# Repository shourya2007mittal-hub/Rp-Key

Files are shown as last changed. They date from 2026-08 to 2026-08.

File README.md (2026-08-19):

# Rp-Key



SO I wanted to make something like YubiKey but to Enter passwords onto your online accounts or offline password ( like laptop passwords / security passwords) and the most important thing that I focused was that you could enter a password in public without anyone watching it . This add extra privacy to your workflow . So the main focus of my design was to make it small . SO I used RP2350A as micro-controller because it doesn't need an external oscillator hence it saves space on the board . Also there are 4 switches . So you could enter upto 4 different passwords as per your need . There is a boot pin also so that you could update the board as per your need .  The Design is compatible with USB-A and it plugs in perfectly onto it with all the connectors pins aligned . other then that the board has a 3.3V voltage regulator for the MCU and a LED. 

## Why This

It is a simple and is compile too that can be directly plugged on Laptop to enter a password also no one would see you entering the password so it's even better. 

## Features

- Based on RP-2035A Chip
- Has MCP1700x-330xxTT as Voltage Regulator
- has 4 button to enter 4 different password
- had a boot pin as well to update password
- Plugs directly onto type A female

# Project Bill of Materials (BOM) & Cost Summary

## 📦 Components List

| Comment / Part | Quantity | Total Price ($) | Part Link |
| :--- | :---: | :---: | :--- |
| **4.7u** | 6 | $0.1368 | [JLCPCB Link](https://jlcpcb.com/partdetail/24469-CL05A475MP5NRNC/C23733) |
| **100n** | 4 | $0.0216 | [JLCPCB Link](https://jlcpcb.com/partdetail/1877-CL05B104KO5NNNC/C1525) |
| **10uF** | 4 | $0.1548 | [JLCPCB Link](https://jlcpcb.com/partdetail/20411-CL10A106KP8NNNC/C19702) |
| **15p** | 4 | $0.0188 | [JLCPCB Link](https://jlcpcb.com/partdetail/1900-0402CG150J500NT/C1548) |
| **3.3u** | 2 | $1.6456 | [JLCPCB Link](https://jlcpcb.com/partdetail/KOHERelec-MDA40203R3M/C2847470) |
| **1k** | 4 | $0.0320 | [JLCPCB Link](https://jlcpcb.com/partdetail/12256-0402WGF1001TCE/C11702) |
| **10k** | 2 | $0.0132 | [JLCPCB Link](https://jlcpcb.com/partdetail/26274-0402WGJ0103TCE/C25531) |
| **27 ohm** | 4 | $0.0362 | [JLCPCB Link](https://jlcpcb.com/partdetail/25843-0402WGF270JTCE/C25100) |
| **33** | 2 | $0.0068 | [JLCPCB Link](https://jlcpcb.com/partdetail/25848-0402WGF330JTCE/C25105) |
| **1K** | 2 | $0.0120 | [JLCPCB Link](https://jlcpcb.com/partdetail/21904-0603WAF1001T5E/C21190) |
| **SW_Push** | 10 | $3.7180 | [JLCPCB Link](https://jlcpcb.com/partdetail/Korean_HropartsElec-K5_1672SN01/C502360) |
| **RP2350A** | 2 | $3.3980 | [JLCPCB Link](https://jlcpcb.com/partdetail/RaspberryPi-RP2350A/C42411118) |
| **MCP1700x-330xxTT** | 2 | $1.0314 | [JLCPCB Link](https://jlcpcb.com/partdetail/MicrochipTech-MCP1700_3002ETO/C185558) |
| **ABM8-272-T3** | 5 | $1.4705 | [JLCPCB Link](https://jlcpcb.com/partdetail/AbraconLLC-ABM8_272T3/C20625731) |
| **USB_A_PCB_Edge_receptacle** | - | - | - |

---

## 💰 Charge Details & Manufacturing Breakdown

### 🛠️ PCB Fabrication & Assembly Fees
| Item / Description | Price ($) |
| :--- | :---: |
| **PCB Base Price** | $2.00 |
| **Via Covering** | $0.00 |
| **Special Offer** | $2.00 |
| **Setup Fee** | $8.18 |
| **Stencil** | $1.53 |
| **Panel** | $0.00 |
| **Large Size** | $0.00 |
| **Components (12 items)** | $11.65 |
| **Extended components fee** | $12.28 |
| **SMT Assembly** | $0.38 |
| **Hand-soldering labor fee** | $3.58 |
| **Manual Assembly** | $0.10 |
| **Nitrogen reflow soldering** | $0.85 |

### 💵 Cost Totals Summary
| Category | Total Price ($) |
| :--- | :---: |
| **PCB Price Total** | **$2.00** |
| **PCB Shipping** | **$9.68** |
| **Economic PCBA Price Total** | **$48.23** |
| **Grand Total** | **$50.23** |

### Schematic 
<br>



<br>

### PCB Design



### 3D Design



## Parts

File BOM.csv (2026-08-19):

Comment / Item | Quantity | Total Price ($) | Link
4.7u | 6 | 0.1368 | https://jlcpcb.com/partdetail/24469-CL05A475MP5NRNC/C23733
100n | 4 | 0.0216 | https://jlcpcb.com/partdetail/1877-CL05B104KO5NNNC/C1525
10uF | 4 | 0.1548 | https://jlcpcb.com/partdetail/20411-CL10A106KP8NNNC/C19702
10uF | 6 | 0.1548 | https://jlcpcb.com/partdetail/20411-CL10A106KP8NNNC/C19702
15p | 4 | 0.0188 | https://jlcpcb.com/partdetail/1900-0402CG150J500NT/C1548
3.3u | 2 | 1.6456 | https://jlcpcb.com/partdetail/KOHERelec-MDA40203R3M/C2847470
1k | 4 | 0.0320 | https://jlcpcb.com/partdetail/12256-0402WGF1001TCE/C11702
33 | 2 | 0.0068 | https://jlcpcb.com/partdetail/25848-0402WGF330JTCE/C25105
1K | 2 | 0.0120 | https://jlcpcb.com/partdetail/21904-0603WAF1001T5E/C21190
10k | 2 | 0.0132 | https://jlcpcb.com/partdetail/26274-0402WGJ0103TCE/C25531
27 ohm | 4 | 0.0362 | https://jlcpcb.com/partdetail/25843-0402WGF270JTCE/C25100
SW_Push | 4 | 3.7180 | https://jlcpcb.com/partdetail/Korean_HropartsElec-K5_1672SN01/C502360
RP2350A | 2 | 3.3980 | https://jlcpcb.com/partdetail/RaspberryPi-RP2350A/C42411118
MCP1700x-330xxTT | 2 | 1.0314 | https://jlcpcb.com/partdetail/MicrochipTech-MCP1700_3002ETO/C185558
ABM8-272-T3 | 5 | 1.4705 | https://jlcpcb.com/partdetail/AbraconLLC-ABM8_272T3/C20625731
USB_A_PCB_Edge_receptacle | - | - | -
--- CHARGE DETAILS --- | --- | --- | ---
PCB Base Price | - | 2.00 | -
Via Covering | - | 0.00 | -
Special Offer | - | 2.00 | -
Setup Fee | - | 8.18 | -
Stencil | - | 1.53 | -
Panel | - | 0.00 | -
Large Size | - | 0.00 | -
Components (12 items) | - | 11.65 | -
Extended components fee | - | 12.28 | -
SMT Assembly | - | 0.38 | -
Hand-soldering labor fee | - | 3.58 | -
Manual Assembly | - | 0.10 | -
Nitrogen reflow soldering | - | 0.85 | -
PCB Price Total | - | 2.00 | -
PCB Shipping | - | 9.68 | -
Economic PCBA Price Total | - | 48.23 | -
Grand Total | - | 50.23 | -

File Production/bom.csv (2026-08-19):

Designator | Footprint | Quantity | Value | LCSC Part #
C1, C2, C3 | 0402 | 3 | 4.7u
C6, C7, C8, C9, C10, C11 | 0402 | 6 | 10uf
C13, C14 | 0603 | 2 | 10uF
C29, C30 | 0402 | 2 | 15p
C4, C5 | 0402 | 2 | 100n
D1 | 0201 | 1 | LED
J1 | USB_A_PCB_Edge_receptacle | 1 | USB_A_PCB_Edge_receptacle
L1 | 0402 | 1 | 3.3u
R1, R2 | 0402 | 2 | 1k
R11 | 0603 | 1 | 1K
R3 | 0402 | 1 | 33
R5 ,R6 | 0402 | 2 | 27 ohm
SW13, SW14 | SW_Tactile_SPST_NO_Straight_CK_PTS636Sx25SMTRLFS | 2 | SW_Push
U1 | QFN-60-1EP_7x7mm_P0.4mm_EP3.4x3.4mm | 1 | RP2350A
U3 | SOT-23 | 1 | MCP1700x-330xxTT
Y2 | Crystal_SMD_3225-4Pin_3.2x2.5mm | 1 | ABM8-272-T3

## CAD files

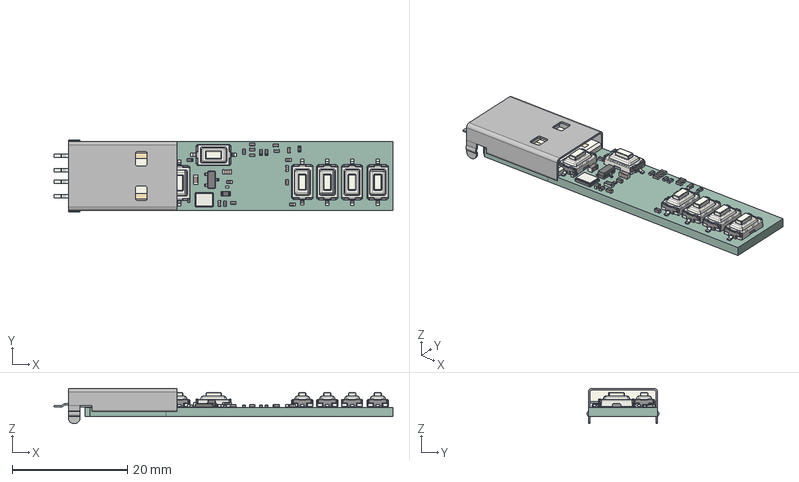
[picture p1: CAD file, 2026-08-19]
CAD/RP-KEY.step
58.8 x 12.5 x 6.10 mm
L_0402_1005Metric
C_0402_1005Metric x 13
C_0603_1608Metric x 2
R_0603_1608Metric
PTS636Sx25SMTRLFS x 6
R_0402_1005Metric x 6
Crystal_SMD_3225-4Pin_3.2x2.5mm
USB_A_CNCTech_1001-011-01101_Horizontal
SOT-23
LED_0201_0603Metric
RP-9DD9_PCB

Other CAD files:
CAD/RP-KEY.f3d

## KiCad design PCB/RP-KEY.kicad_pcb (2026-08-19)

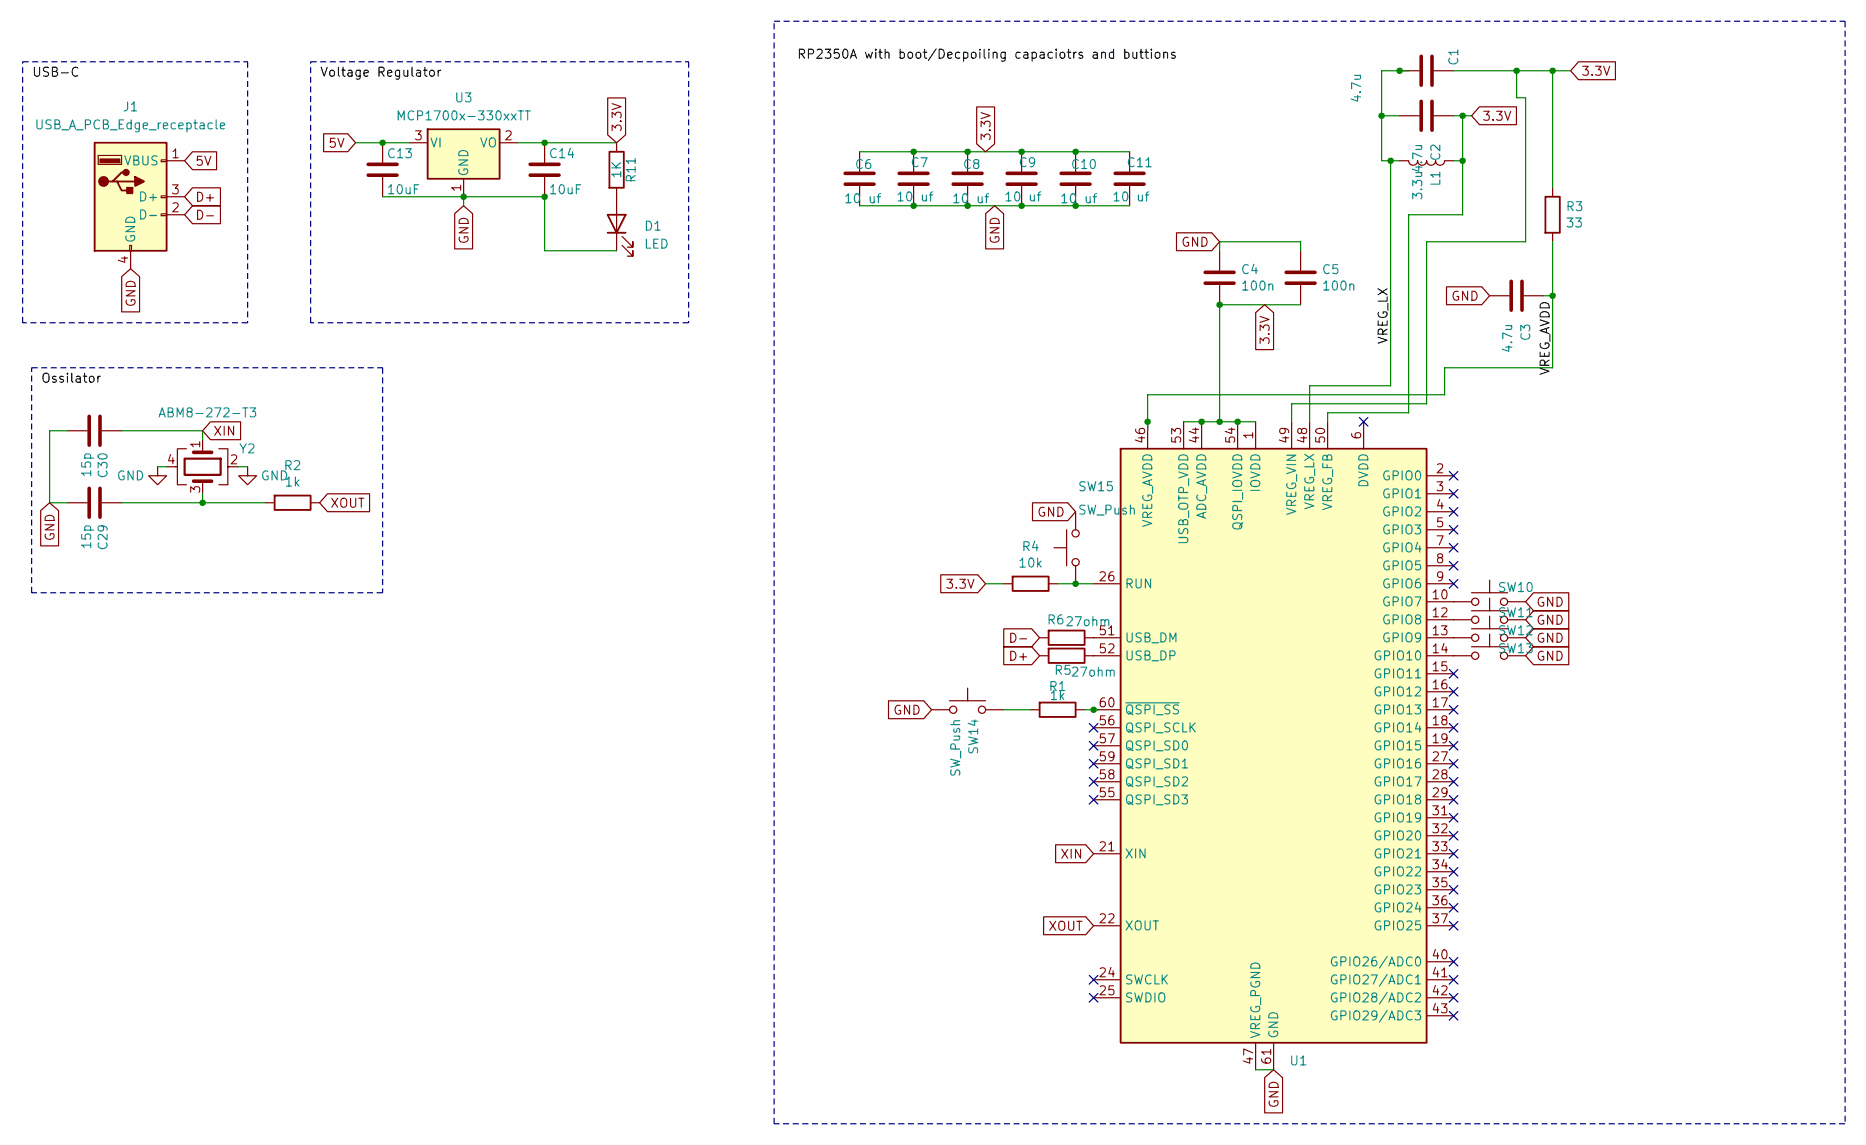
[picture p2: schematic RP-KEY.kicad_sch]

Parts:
C1, C2, C3: 4.7u; C_0402_1005Metric
C4, C5: 100n; C_0402_1005Metric
C6, C7, C8, C9, C10, C11: 10 uf; C_0402_1005Metric
C13, C14: 10uF; C_0603_1608Metric
C29, C30: 15p; C_0402_1005Metric
D1: LED; LED_0201_0603Metric
J1: USB_A_PCB_Edge_receptacle
L1: 3.3u; L_0402_1005Metric_Pad0.77x0.64mm_HandSolder
R1, R2: 1k; R_0402_1005Metric
R3: 33; R_0402_1005Metric
R4: 10k; R_0402_1005Metric
R5, R6: 27ohm; R_0402_1005Metric
R11: 1K; R_0603_1608Metric
SW10, SW11, SW12, SW13, SW14, SW15: SW_Push; SW_Tactile_SPST_NO_Straight_CK_PTS636Sx25SMTRLFS
U1: RP2350A; QFN-60-1EP_7x7mm_P0.4mm_EP3.4x3.4mm
U3: MCP1700x-330xxTT; SOT-23
Y2: ABM8-272-T3; Crystal_SMD_3225-4Pin_3.2x2.5mm

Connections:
3.3V: C1.1, C2.1, C4.2, C5.2, C6.1, C7.1, C8.1, C9.1, C10.1, C11.1, C14.1, L1.1, R3.1, R4.2, R11.1, U1.1 (IOVDD), U1.11 (IOVDD), U1.20 (IOVDD), U1.30 (IOVDD), U1.38 (IOVDD), U1.44 (ADC_AVDD), U1.45 (IOVDD), U1.49 (VREG_VIN), U1.50 (VREG_FB), U1.53 (USB_OTP_VDD), U1.54 (QSPI_IOVDD), U3.2 (VO)
5V: C13.1, J1.1 (VBUS), U3.3 (VI)
/VREG_AVDD: C3.1, R3.2, U1.46 (VREG_AVDD)
/VREG_LX: C1.2, C2.2, L1.2, U1.48 (VREG_LX)
D+: J1.3 (D+), R5.2
D-: J1.2 (D-), R6.2
GND: C3.2, C4.1, C5.1, C6.2, C7.2, C8.2, C9.2, C10.2, C11.2, C13.2, C14.2, C29.2, C30.2, D1.1 (K), J1.4 (GND), SW10.2, SW11.2, SW12.2, SW13.2, SW14.1, SW15.2, U1.47 (VREG_PGND), U1.61 (GND), U3.1 (GND), Y2.2, Y2.4
unnamed: C29.1, R2.2, Y2.3
unnamed: D1.2 (A), R11.2
unnamed: R1.2, SW14.2
unnamed: SW10.1, U1.10 (GPIO7)
unnamed: SW11.1, U1.12 (GPIO8)
unnamed: SW12.1, U1.13 (GPIO9)
unnamed: SW13.1, U1.14 (GPIO10)
unnamed: R4.1, SW15.1, U1.26 (RUN)
unnamed: R6.1, U1.51 (USB_DM)
unnamed: R5.1, U1.52 (USB_DP)
unnamed: R1.1, U1.60 (~QSPI_SS)
XIN: C30.1, U1.21 (XIN), Y2.1
XOUT: R2.1, U1.22 (XOUT)

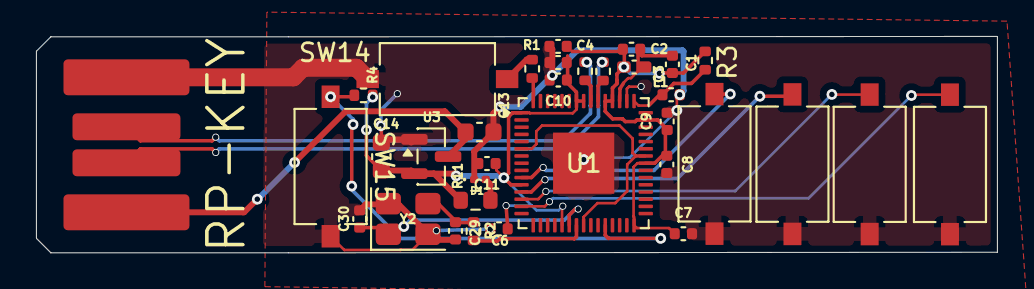
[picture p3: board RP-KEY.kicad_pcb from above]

Board: 2 copper layers, 53.4 x 12.0 mm, 34 parts (0 on the bottom side), 20 nets.
